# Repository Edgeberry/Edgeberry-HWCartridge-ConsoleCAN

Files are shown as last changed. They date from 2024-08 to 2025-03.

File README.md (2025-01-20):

Edgeberry banner

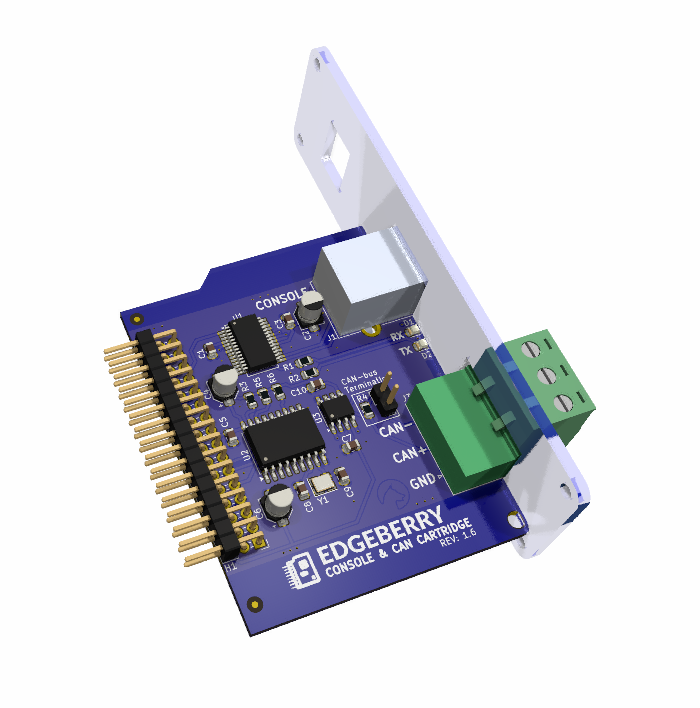
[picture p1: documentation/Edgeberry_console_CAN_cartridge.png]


The Edgeberry **Console & CAN Hardware Cartridge** allows you to use your Edgeberry device in a wide range of industrial applications. The CAN-bus is utilized in diverse fields, from medical equipment to heavy industrial machinery. Additionally, the USB interface provides access to your Raspberry Pi's console, enabling direct local control over your device.

<br clear="right"/>

## Usage

### Console
Configure your Raspberry Pi to enable console access on the UART with `raspi-config`, or by manually adding following lines the boot configuration file `/boot/firmware/config.txt`:
```
enable_uart=1
dtparam=uart0
dtparam=uart0_console
```
Now `reboot` the device to apply these settings.

Connect to your Edgeberry device with your computer system, and open a terminal emulation program (e.g. minicom, PuTTY) with the following settings
```
Speed: 115200 baud
Bits: 8
Parity: None
Stop Bits: 1
Flow Control: None
```
If this went well, you now have access to your Edgeberry's console.

### CAN-bus
To enable the CAN interface, add the following lines the boot configuration file `/boot/firmware/config.txt`:
```
# CAN interface
dtoverlay=mcp2515-can0,oscillator=16000000,interrupt=25
```
And reboot your device. After rebooting, set up the CAN interface 
```
sudo ip link set can0 up type can bitrate 500000
```
Now you can see the `can0` interface when running `ifconfig`.

#### Resources
https://github.com/iDoka/awesome-canbus<br/>
https://www.beyondlogic.org/adding-can-controller-area-network-to-the-raspberry-pi/<br/>
https://www.hackster.io/youness/how-to-connect-raspberry-pi-to-can-bus-b60235<br/>
http://lnxpps.de/rpie/

## License & Collaboration
**Copyright© 2024 Sanne 'SpuQ' Santens**. This project is released under the **CERN OHL-W** license. The [Rules & Guidelines](https://github.com/Edgeberry/.github/blob/main/brand/Edgeberry_Trademark_Rules_and_Guidelines.md) apply to the usage of the Edgeberry™ brand.

### Collaboration

If you'd like to contribute to this project, please follow these guidelines:
1. Fork the repository and create your branch from `main`.
2. Make your changes and ensure they adhere to the project's design style and conventions.
3. Test your changes thoroughly.
4. Ensure your commits are descriptive and well-documented.
5. Open a pull request, describing the changes you've made and the problem or feature they address.

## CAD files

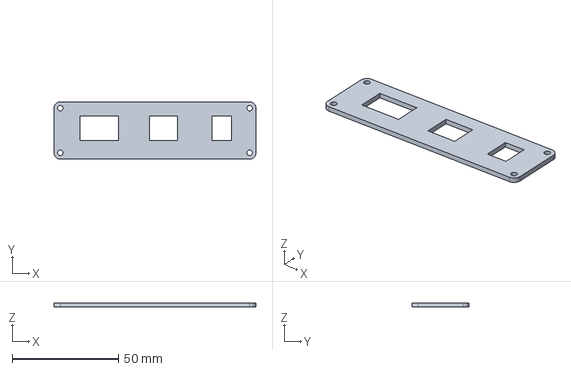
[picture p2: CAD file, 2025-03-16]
documentation/Edgeberry_console_cartridge_faceplate.step
95.0 x 27.0 x 2.00 mm

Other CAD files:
Edgeberry_console_cartridge_faceplate.FCStd

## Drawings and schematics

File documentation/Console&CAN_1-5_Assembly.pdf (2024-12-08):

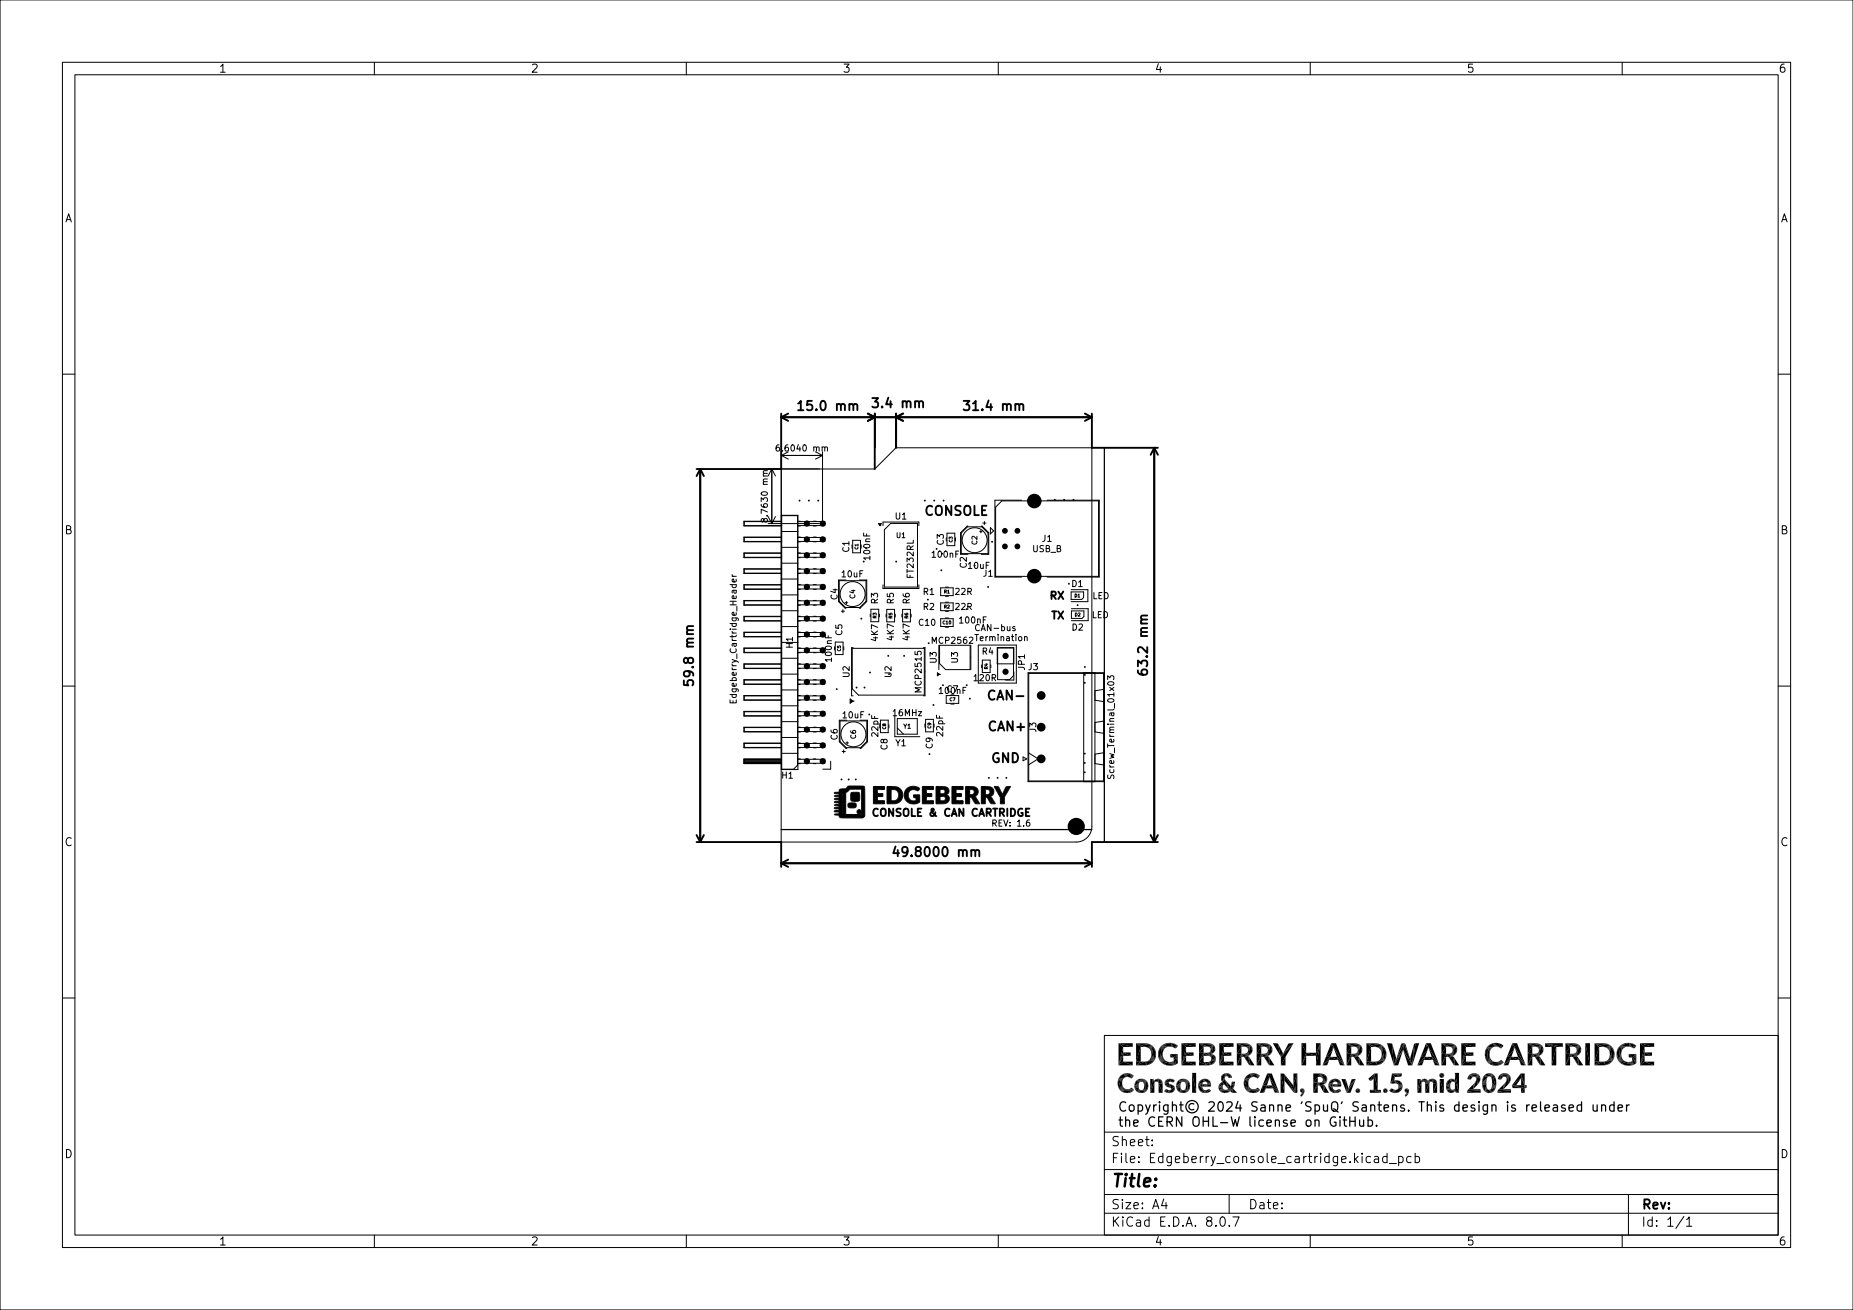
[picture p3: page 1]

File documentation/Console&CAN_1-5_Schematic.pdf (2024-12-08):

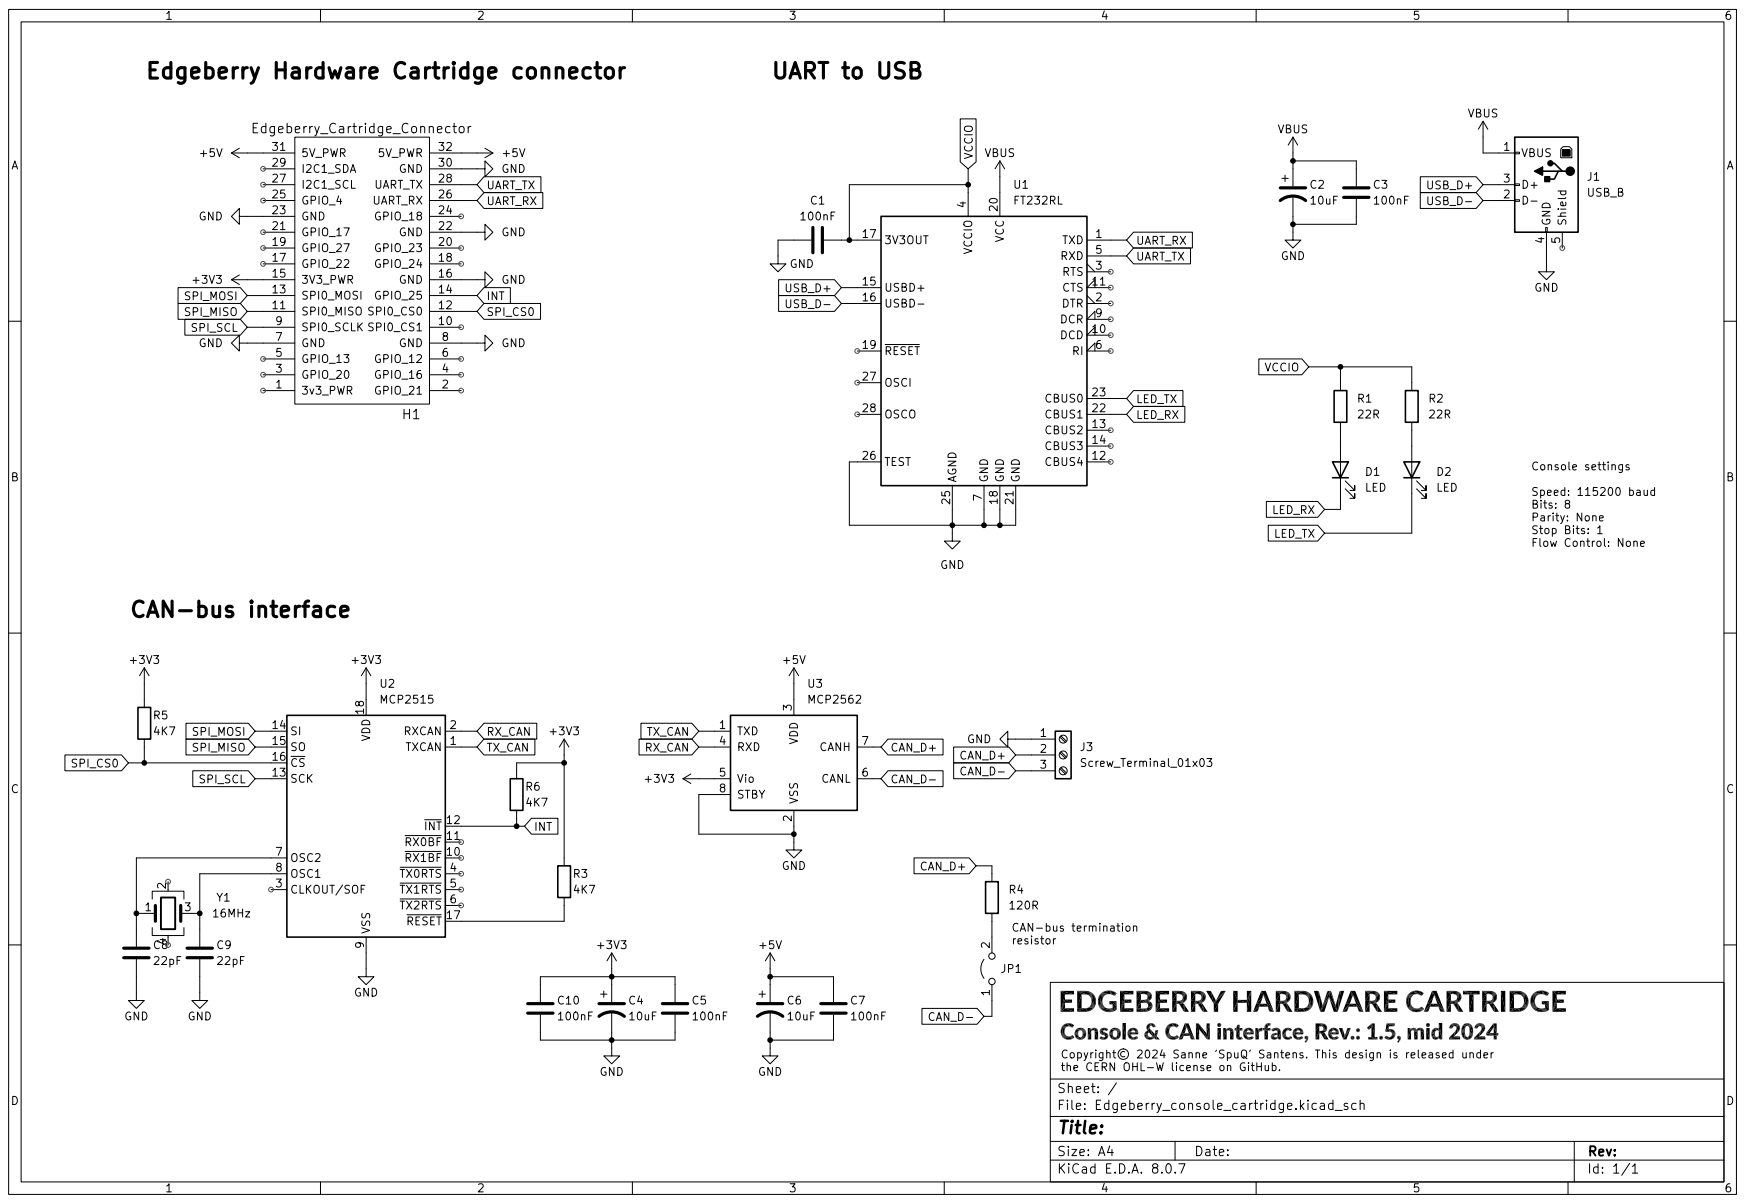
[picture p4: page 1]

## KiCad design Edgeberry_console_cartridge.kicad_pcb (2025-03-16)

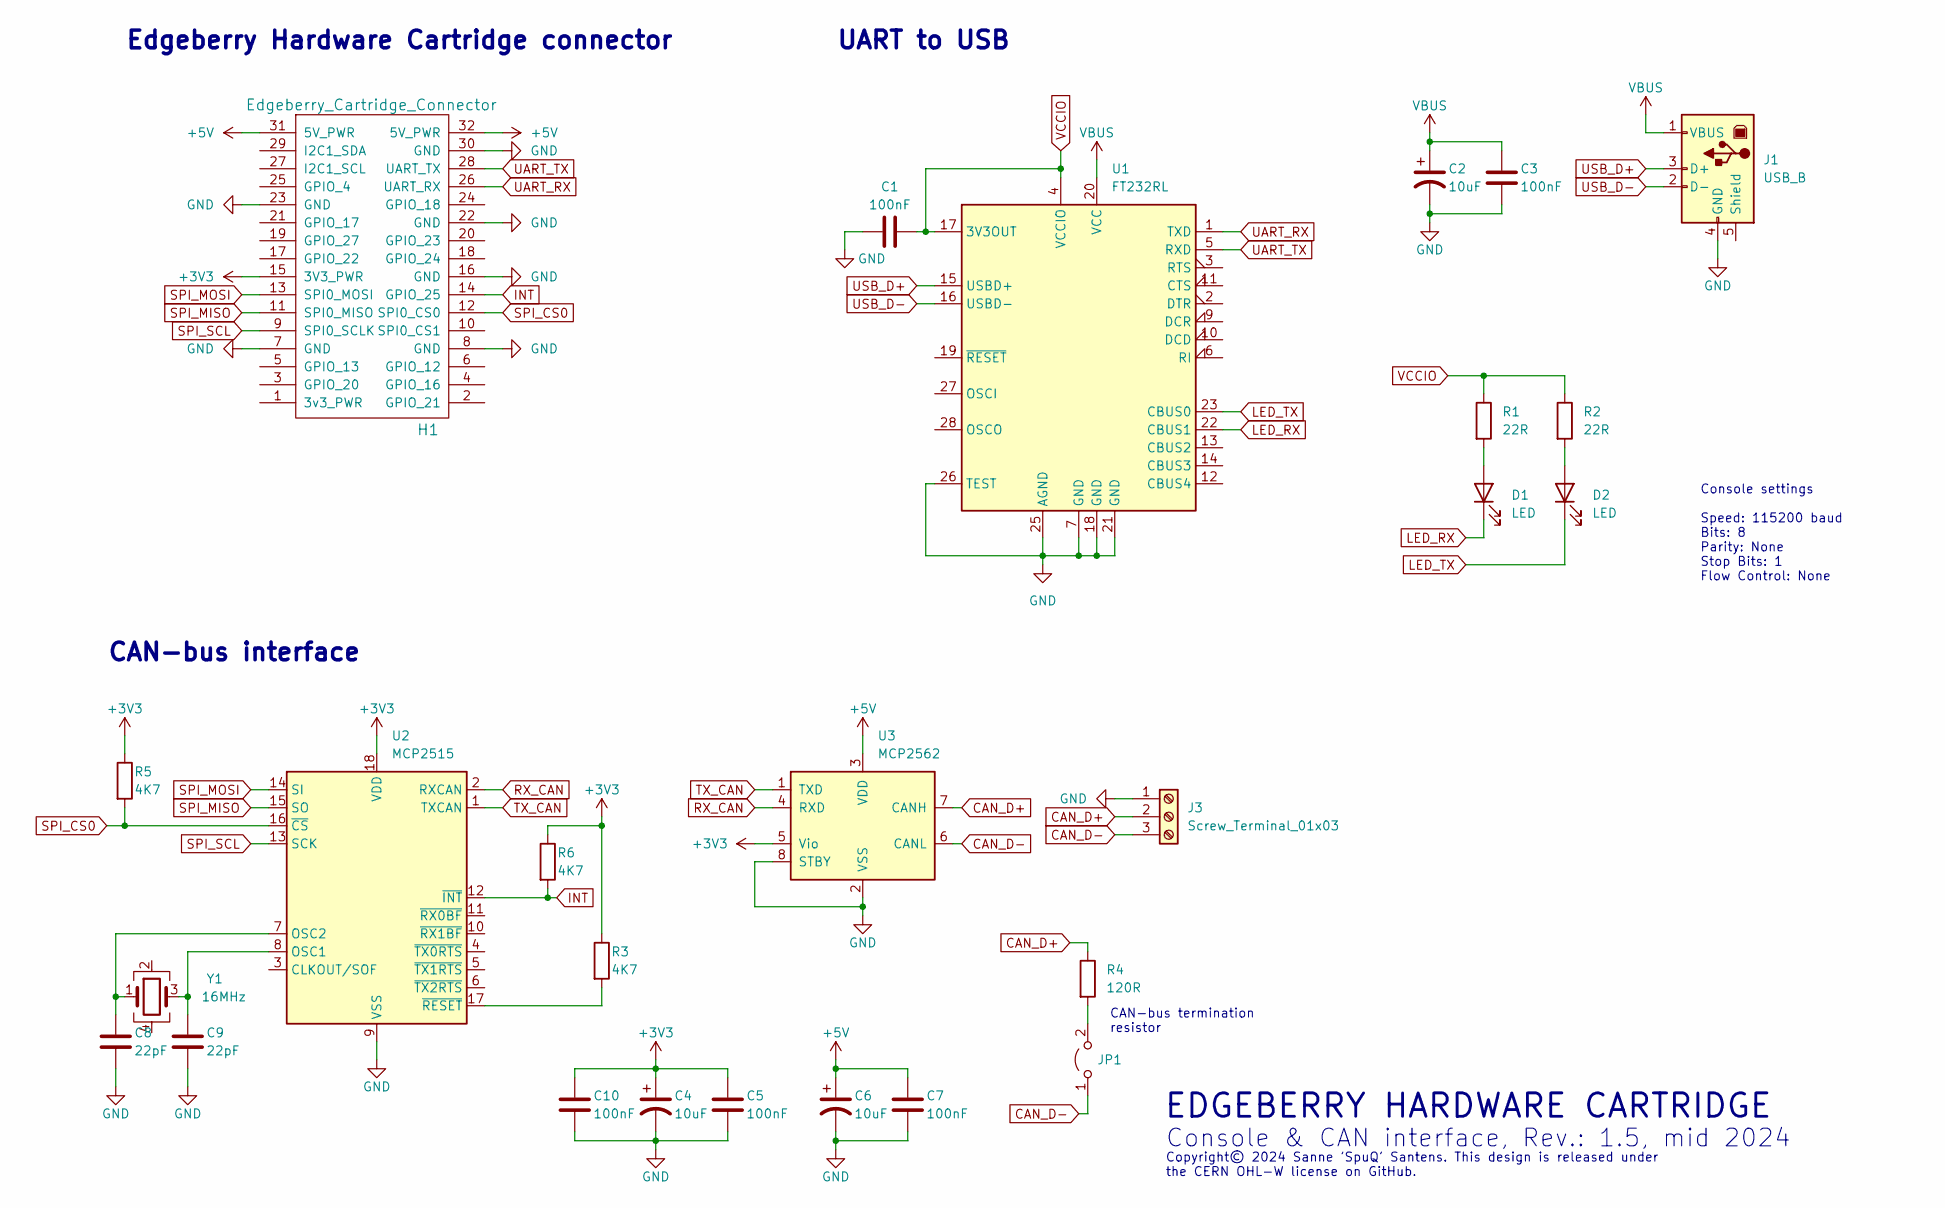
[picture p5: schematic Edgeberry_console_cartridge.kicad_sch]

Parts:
C1, C3, C5, C7, C10: 100nF; C_0805_2012Metric
C2, C4, C6: 10uF; CP_Elec_4x5.4
C8, C9: 22pF; C_0805_2012Metric
D1, D2: LED; LED_0805_2012Metric
H1: Edgeberry_Cartridge_Connector; PinHeader_2x16_P2.54mm_Horizontal
J1: USB_B; USB_B_OST_USB-B1HSxx_Horizontal
J3: Screw_Terminal_01x03; PhoenixContact_MSTBA_2,5_3-G-5,08_1x03_P5.08mm_Horizontal
JP1: Jumper_2_Open; PinHeader_1x02_P2.54mm_Vertical
R1, R2: 22R; R_0805_2012Metric
R3, R5, R6: 4K7; R_0805_2012Metric
R4: 120R; R_0805_2012Metric
U1: FT232RL; SSOP-28_5.3x10.2mm_P0.65mm
U2: MCP2515; SOIC-18W_7.5x11.6mm_P1.27mm
U3: MCP2562; SOIC-8_3.9x4.9mm_P1.27mm
Y1: 16MHz; Crystal_SMD_3225-4Pin_3.2x2.5mm

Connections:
+3V3: C4.1, C5.1, C10.1, H1.15 (3V3_PWR), R3.1, R5.1, R6.1, U2.18 (VDD), U3.5 (Vio)
+5V: C6.1, C7.1, H1.31 (5V_PWR), H1.32 (5V_PWR), U3.3 (VDD)
CAN_D+: J3.2, R4.1, U3.7 (CANH)
CAN_D-: J3.3, JP1.1 (A), U3.6 (CANL)
GND: C1.1, C2.2, C3.2, C4.2, C5.2, C6.2, C7.2, C8.2, C9.2, C10.2, H1.6 (GPIO_12), H1.7 (GND), H1.8 (GND), H1.16 (GND), H1.22 (GND), H1.23 (GND), H1.30 (GND), J1.4 (GND), J3.1, U1.7 (GND), U1.18 (GND), U1.21 (GND), U1.25 (AGND), U1.26 (TEST), U2.9 (VSS), U3.2 (VSS), U3.8 (STBY)
INT: H1.14 (GPIO_25), R6.2, U2.12 (~INT)
LED_RX: D1.1 (K), U1.22 (CBUS1)
LED_TX: D2.1 (K), U1.23 (CBUS0)
unnamed: D1.2 (A), R1.2
unnamed: D2.2 (A), R2.2
unnamed: JP1.2 (B), R4.2
unnamed: C9.1, U2.8 (OSC1), Y1.3
unnamed: C8.1, U2.7 (OSC2), Y1.1
unnamed: R3.2, U2.17 (~RESET)
RX_CAN: U2.2 (RXCAN), U3.4 (RXD)
SPI_CS0: H1.12 (SPI0_CS0), R5.2, U2.16 (~CS)
SPI_MISO: H1.11 (SPI0_MISO), U2.15 (SO)
SPI_MOSI: H1.13 (SPI0_MOSI), U2.14 (SI)
SPI_SCL: H1.9 (SPI0_SCLK), U2.13 (SCK)
TX_CAN: U2.1 (TXCAN), U3.1 (TXD)
UART_RX: H1.26 (UART_RX), U1.1 (TXD)
UART_TX: H1.28 (UART_TX), U1.5 (RXD)
USB_D+: J1.3 (D+), U1.15 (USBD+)
USB_D-: J1.2 (D-), U1.16 (USBD-)
VBUS: C2.1, C3.1, J1.1 (VBUS), U1.20 (VCC)
VCCIO: C1.2, R1.1, R2.1, U1.4 (VCCIO), U1.17 (3V3OUT)

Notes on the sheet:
CAN-bus interface
EDGEBERRY HARDWARE CARTRIDGE
UART to USB
Console & CAN interface, Rev.: 1.5, mid 2024
Copyright© 2024 Sanne 'SpuQ' Santens. This design is released under the CERN OHL-W license on GitHub.
CAN-bus termination resistor
Edgeberry Hardware Cartridge connector
Console settings Speed: 115200 baud Bits: 8 Parity: None Stop Bits: 1 Flow Control: None

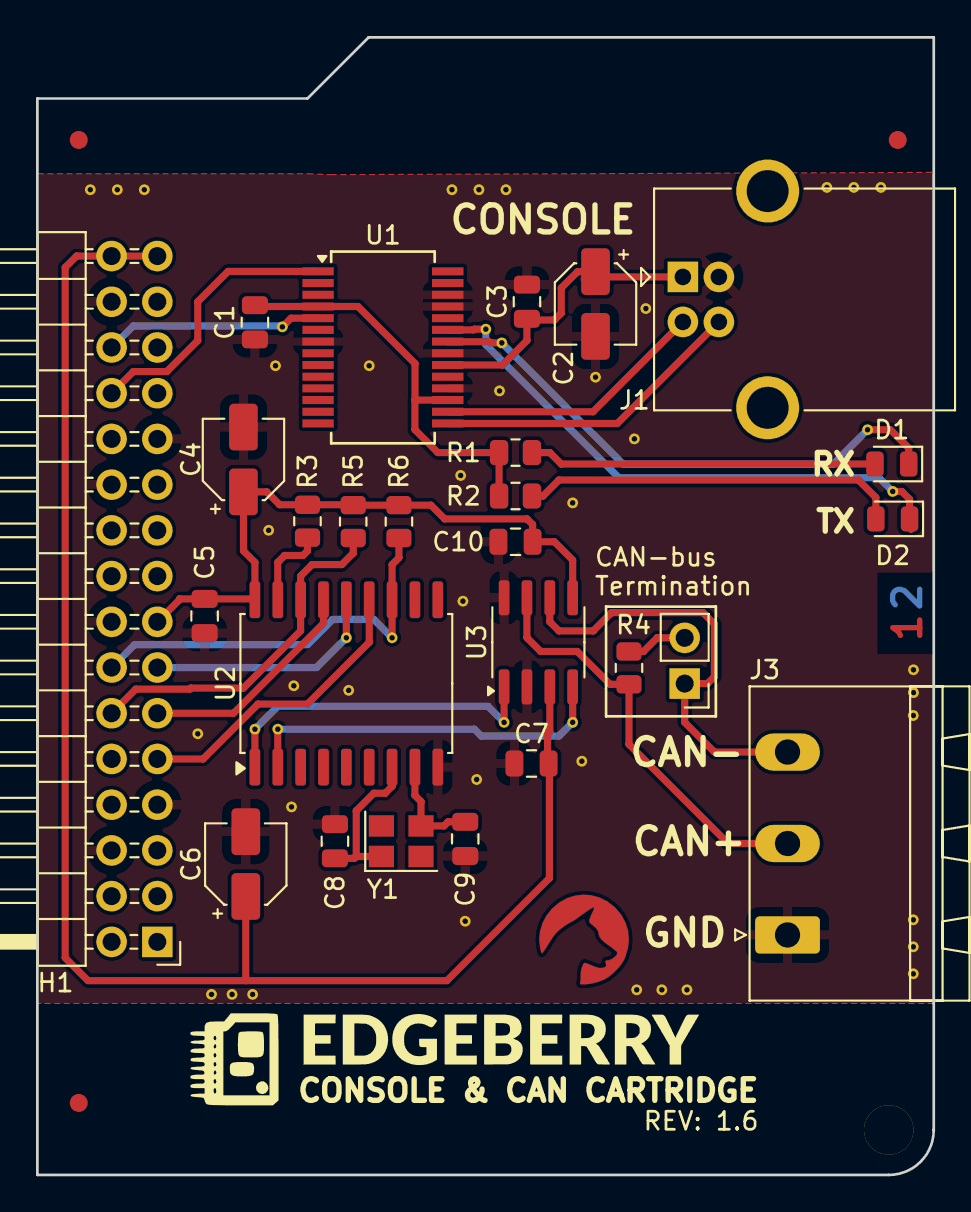
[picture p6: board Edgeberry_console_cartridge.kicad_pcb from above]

Board: 2 copper layers, 49.8 x 63.2 mm, 26 parts (0 on the bottom side), 26 nets.

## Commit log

2024-05-15 Initial commit of the designs
    [Edgeberry_console_cartridge.kicad_pcb, Edgeberry_console_cartridge.kicad_sch]
2024-05-15 ReadMe: better 'insert cartridge' image
2024-05-18 Update to KiCad 8 + footprint cleanup
    [Edgeberry_console_cartridge.kicad_pcb, Edgeberry_console_cartridge.kicad_sch]
2024-05-18 Silk screen improvements
    [Edgeberry_console_cartridge.kicad_pcb]
2024-05-19 Open Source Hardware license: CERN-OHL-W
    [Edgeberry_console_cartridge.kicad_pcb, Edgeberry_console_cartridge.kicad_sch]
2024-08-27 lock connector footprints
    [Edgeberry_console_cartridge.kicad_pcb]
2024-08-27 Cartridge faceplate design
    [Edgeberry_console_cartridge_faceplate.FCStd]
2024-08-29 Faceplate: fix USB dimensions
    [Edgeberry_console_cartridge_faceplate.FCStd]
2024-09-22 Tindie button
2024-11-01 Faceplate: power jack cutout
    [Edgeberry_console_cartridge_faceplate.FCStd]
2024-12-08 Documentation: Schematic + Assembly
2024-12-08 Faceplate: optimization
    [Edgeberry_console_cartridge_faceplate.FCStd]
2025-01-20 ReadMe: Enable UART for console
